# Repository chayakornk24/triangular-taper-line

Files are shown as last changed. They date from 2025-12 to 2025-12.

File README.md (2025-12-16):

# Triangular Taper Transmission Line

This repository contains a complete microwave engineering project
on a triangular taper transmission line, including simulation,
PCB fabrication, and measurement.

The project is documented as a step-by-step report and supported
by simulation and measurement files for reference.

## Project Overview
The work follows a practical engineering workflow:
- Impedance profile design of a triangular taper
- Ideal transmission-line simulation (netlist)
- Electromagnetic geometry simulation
- PCB layout and fabrication
- Measurement using a Vector Network Analyzer (VNA)
- Comparison between simulation and measurement

## Repository Structure
- `report/`
  - Final project report in PDF format (step-by-step explanation)

- `simulation/`
  - Sonnet netlist simulations (ideal models)
  - Sonnet geometry simulations (EM models)
  - Netlist vs geometry comparison

- `measurement/`
  - Measured S-parameter data (.s2p)
  - Measurement and comparison plots

- `pcb/`
  - PCB design information (EasyEDA)
  - Fabrication-related files

## Notes
- The PDF report is self-contained and explains the full process.
- Supporting files in this repository are provided for reference
  and project completeness.

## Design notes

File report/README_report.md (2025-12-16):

# Report (PDF)

This folder contains the final step-by-step project report
for the triangular taper transmission line.

## File
- `Triangular_Taper_Line_Report.pdf`
  - Complete report including:
    - Design workflow
    - Netlist simulation
    - Geometry simulation (original vs expanded box cell)
    - PCB design and fabrication
    - VNA measurement setup and results
    - Simulation vs measurement comparison
    - Summary

## Notes
- The report is self-contained (no external links are required to understand the process).
- Supporting project files are stored in the main repository folders:
  - `simulation/`
  - `measurement/`
  - `pcb/`

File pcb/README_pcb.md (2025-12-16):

The PCB layout of the triangular taper line
was designed using EasyEDA.

Public EasyEDA project link:
https://easyeda.com/editor#project_id=84cbbce2f2da43b88b3fbd5d7b5f4b61

This link allows viewing, modification,
and reproduction of the PCB design.

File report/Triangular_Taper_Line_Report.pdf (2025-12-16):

## Title: Triangular Taper Line Design Course: Microwave Engineering - 01205322 Tools: Sonnet, TXLine2003, EasyEDA, JLCPCB Name: Chayakorn Kaewpinit Student ID: 6610550794 Date: 15/12/2025

## Introduction

### This work designs a Triangular taper transmission line and compares 10-section and 20-section implementations. The process follows a practical engineering

workflow from impedance calculation to simulation and PCB fabrication.

## Design Overview (workflow)

### 1. Compute impedance profile (Triangular taper)

### 2. Sonnet netlist simulation (10 vs 20 sections)

### 3. Convert impedance → physical dimensions using TXLine2003 (W, L, and CPW-G spacing)

### 4. Sonnet geometry simulation (20 sections)

### 5. Export to PCB layout (EasyEDA) and fabricate via JLCPCB

# Impedance profile method

We generate the taper impedance using a Triangular weighting with an exponential impedance mapping from 50 Ω to 100 Ω.

### Midpoint location of each section

xi =

i −

1
2
N

, i = 1,2, … , N

### Triangular cumulative function (piecewise)

G(x) = {

2x

2
| if 0 ≤ x ≤ 0.5
4x − 2x | 2 − 1 if 0.5 < x ≤ 1

}

### Exponential impedance mapping

## Z(x) = Z1 (

Z2
Z1

)

G(x)

## , (Z1 = 50 Ω , Z2 = 100 Ω)

### Worked example (i=1, N=10)

### Midpoint position

x1 =

1 −

1
2
10 = 0.05

### Since x1 ≤ 0.5

G(x1

) = 2x1

2 = 2(0.05)
2 = 0.005

### Compute impedance

Z1 = 50 (

100
50 )

0.005
= 50 ∗ 2

0.005

### Numeric value

2

0.005 = 1.0034717

Z1 = 50(1.0034717) = 50.17 Ω

i | (x_i) | (G(x_i)) | (Z_i) (Ω)
1 | 0.05 | 0.005 | 50.17
2 | 0.15 | 0.045 | 51.59
3 | 0.25 | 0.125 | 54.53
4 | 0.35 | 0.245 | 59.34
5 | 0.45 | 0.405 | 65.97
6 | 0.55 | 0.595 | 74.5
7 | 0.65 | 0.755 | 84.25
8 | 0.75 | 0.875 | 91.78
9 | 0.85 | 0.955 | 96.96
10 | 0.95 | 0.995 | 99.83

# Netlist simulation

The calculated impedances are modeled as cascaded transmission line sections in Sonnet netlist to observe ideal electrical behavior.

### 10 sections

: 10-section taper is close to ideal but still shows ripple / higher reflection.

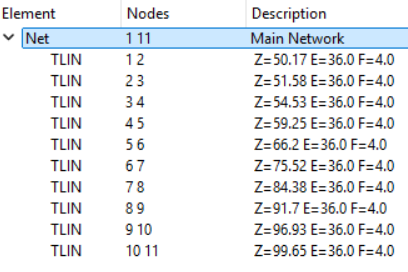
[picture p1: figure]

### 20 sections

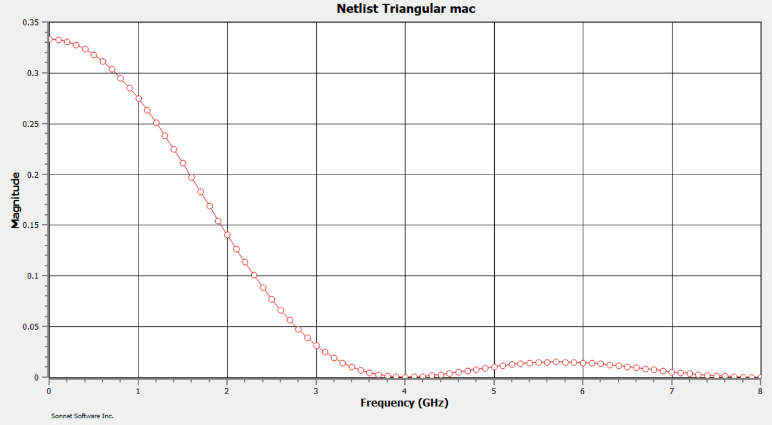
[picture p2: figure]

: 20-section taper reduces reflection and becomes smoother / closer to ideal.

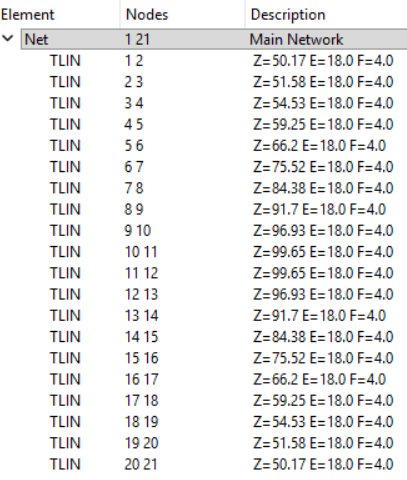
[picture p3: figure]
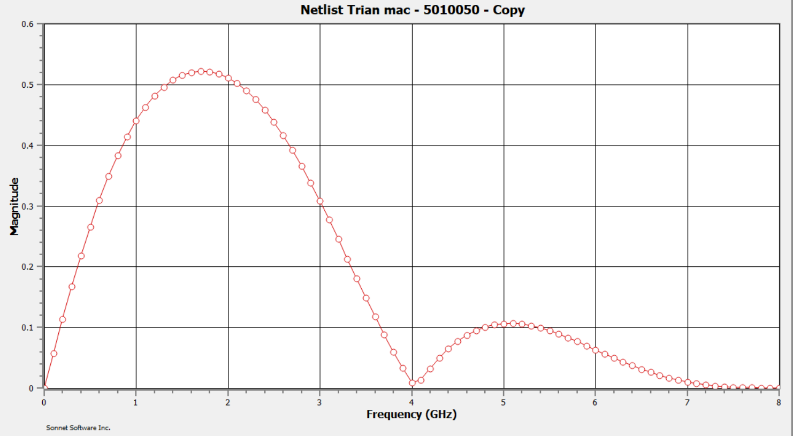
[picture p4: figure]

# Dimensions + CPW-Ground Spacing

### TXLine2003 conversion

The 20-section impedance values are entered into TXLine2003 to obtain physical dimensions under the same substrate settings.

Main outputs used

- Signal width W
- Section length L

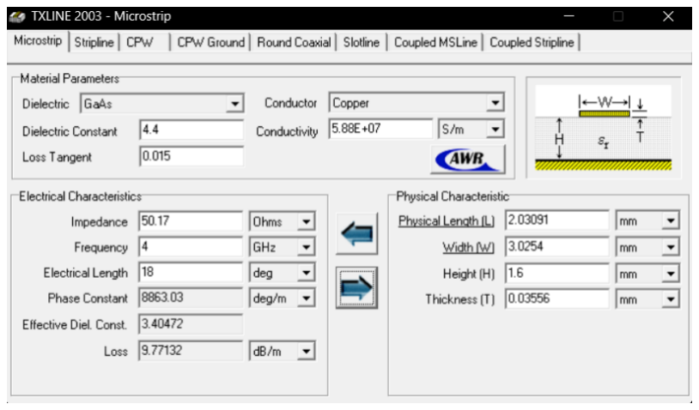
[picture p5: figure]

- For CPW with ground (CPWG): spacing S between the center conductor and both ground conductors (two side grounds)
Impedance | W | L
50.17 | 3.0254 | 2.03091
51.58 | 2.88555 | 2.03577
54.53 | 2.61826 | 2.04565
59.25 | 2.25101 | 2.06064
66.2 | 1.81633 | 2.08099
75.52 | 1.37343 | 2.10539
84.38 | 1.05728 | 2.12572
91.7 | 0.85265 | 2.1407
96.93 | 0.731103 | 2.1506
99.65 | 0.674795 | 2.15554

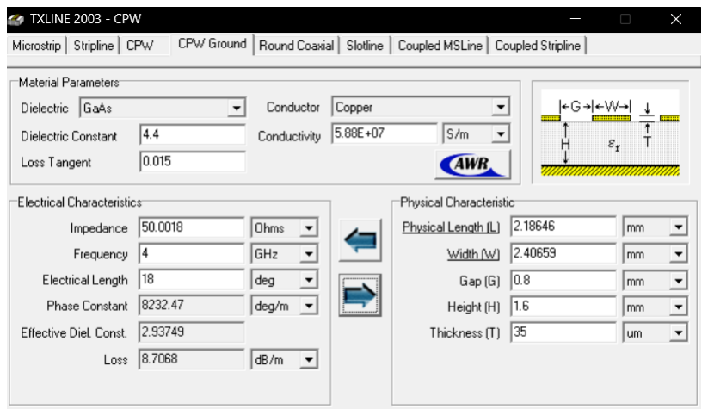
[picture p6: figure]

# Sonnet Geometry Simulation (20 Sections)

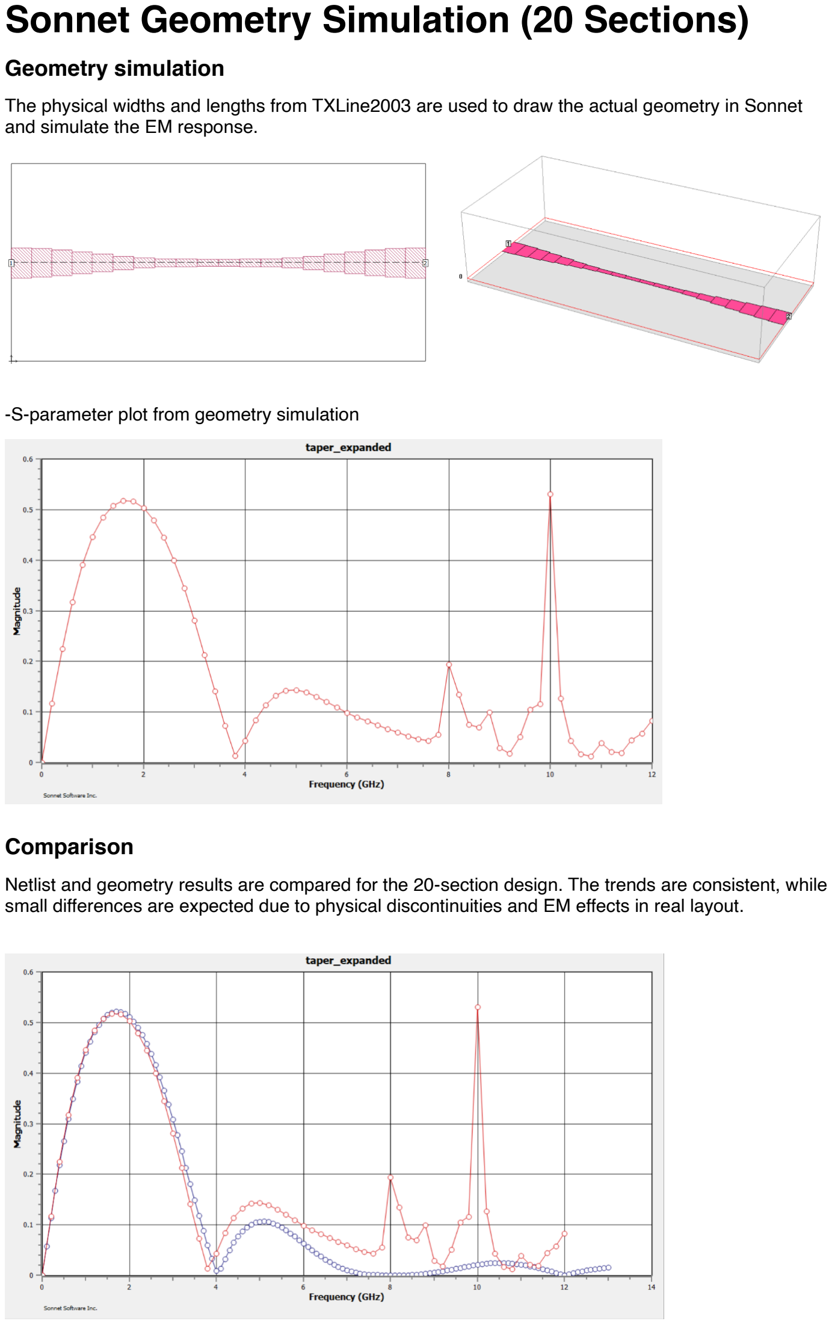
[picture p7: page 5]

### Geometry simulation

The physical widths and lengths from TXLine2003 are used to draw the actual geometry in Sonnet and simulate the EM response.

-S-parameter plot from geometry simulation

### Comparison

Netlist and geometry results are compared for the 20-section design. The trends are consistent, while small differences are expected due to physical discontinuities and EM effects in real layout.

# EasyEDA PCB Layout → JLCPCB

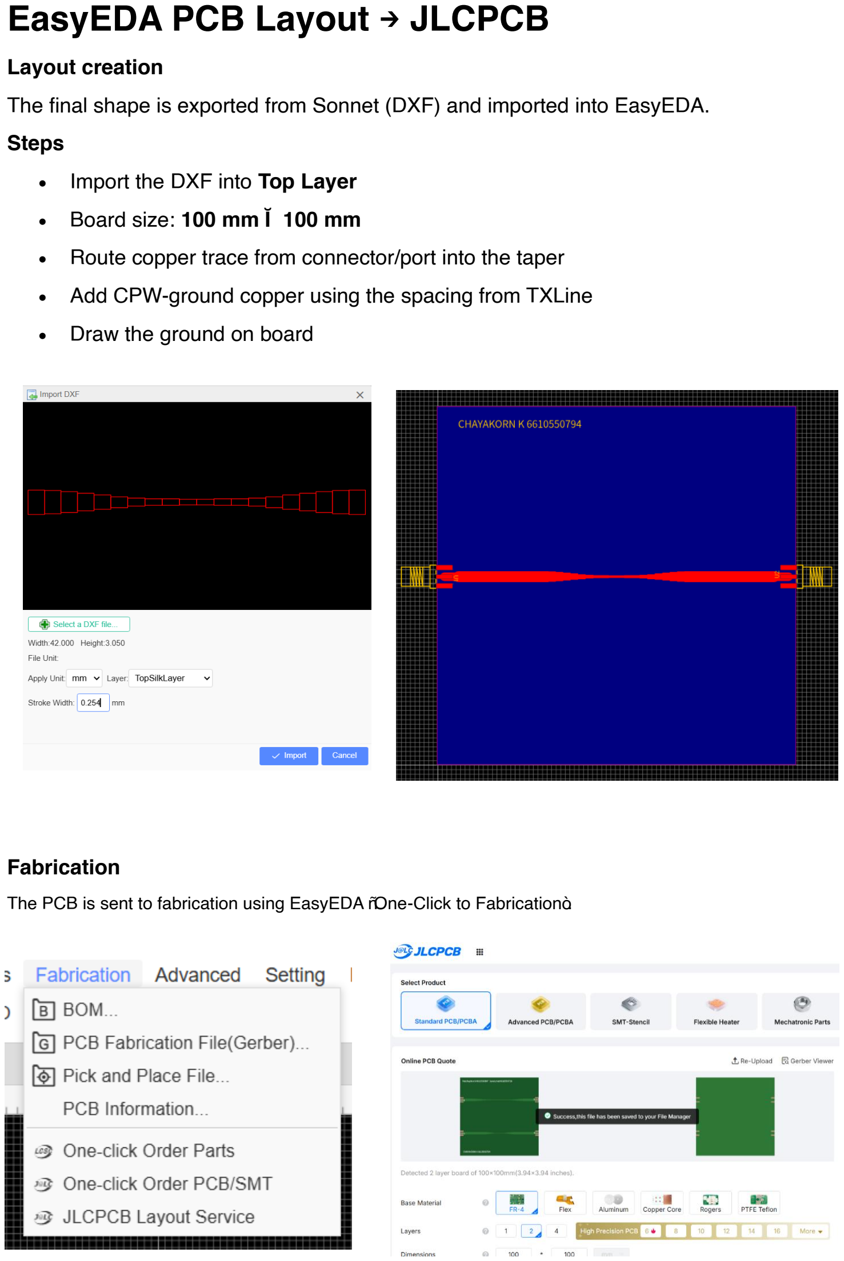
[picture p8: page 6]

### Layout creation

The final shape is exported from Sonnet (DXF) and imported into EasyEDA.

### Steps

### - Import the DXF into Top Layer

### - Board size: 100 mm × 100 mm

### - Route copper trace from connector/port into the taper

### - Add CPW-ground copper using the spacing from TXLine

### - Draw the ground on board

### Fabrication

The PCB is sent to fabrication using EasyEDA “One-Click to Fabrication”.

# PCB Measurement

### PCB Fabrication

This Figure shows the fabricated PCB of the triangular taper line before soldering the connectors. The tapered transmission line was implemented with a continuous change in line width according to the triangular taper profile. This geometry is consistent with the design used in the Sonnet simulation

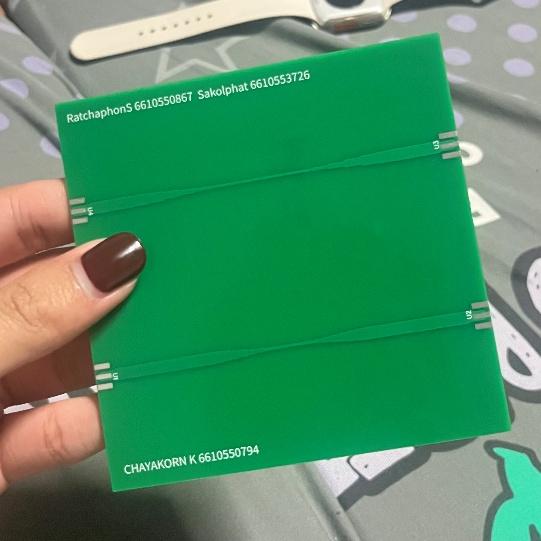
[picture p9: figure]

### Connector Soldering

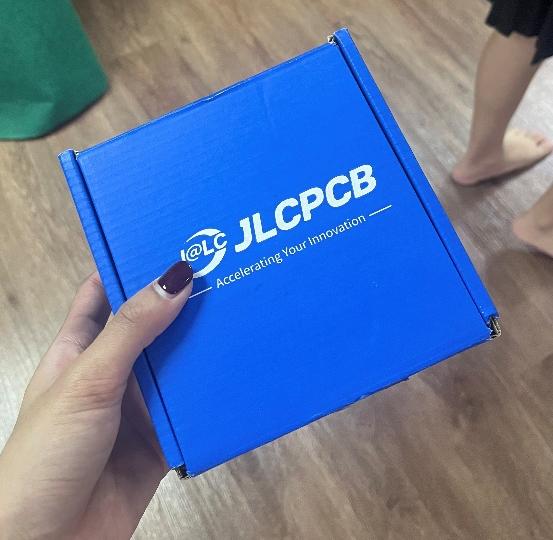
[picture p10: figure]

The SMA connectors were soldered onto the PCB under the supervision of the instructor. Proper soldering is important to ensure good electrical contact and to reduce unwanted effects during measurement.

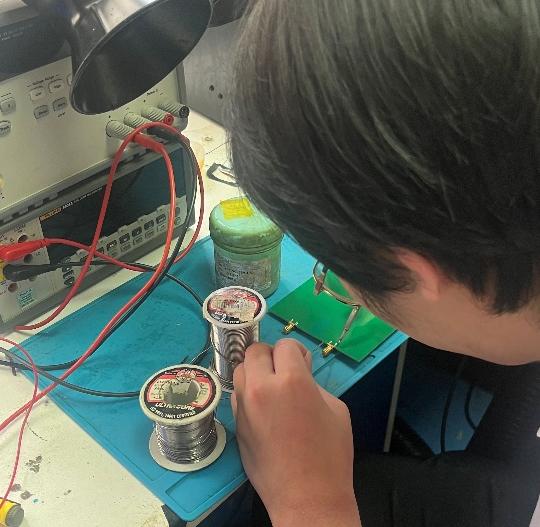
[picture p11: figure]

### Measurement

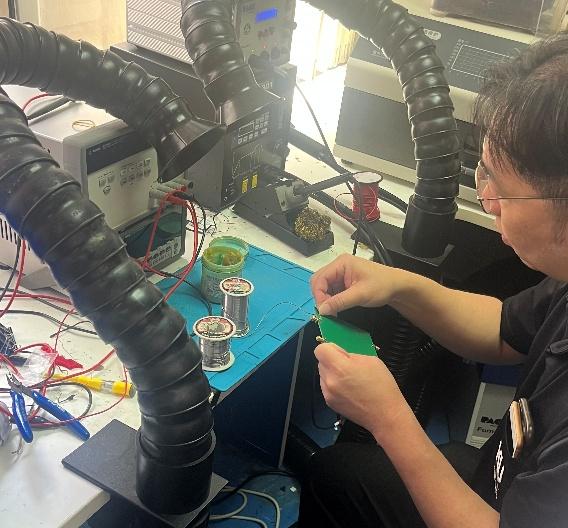
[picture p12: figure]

The fabricated triangular taper line PCB was measured using a Vector Network Analyzer (VNA). The measurement was performed by connecting coaxial cables to both ports of the PCB. The measured S-parameter magnitude represents the real performance of the taper line, including fabrication and measurement effects.

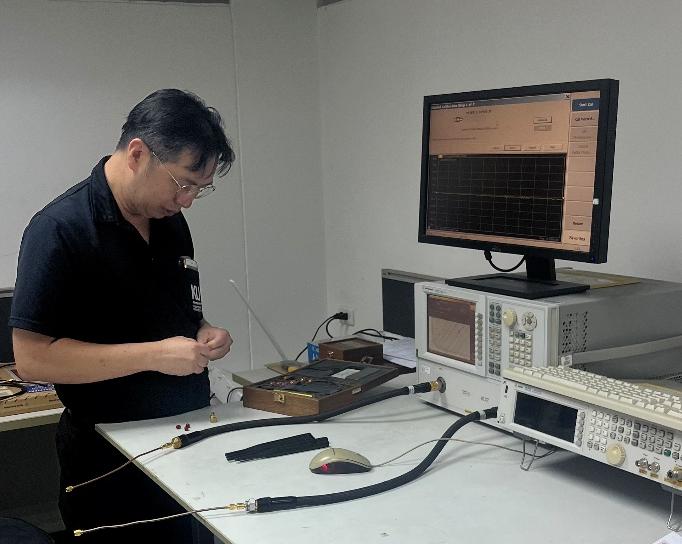
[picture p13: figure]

# Comparison

The measured results are compared with the Sonnet geometry simulation results (red curve) for the 20-section design. The overall trends are in good agreement, showing similar frequency response behavior. Small differences in magnitude and frequency shift are observed, which are expected due to fabrication tolerances, connector effects, and other practical factors in the real measurement.

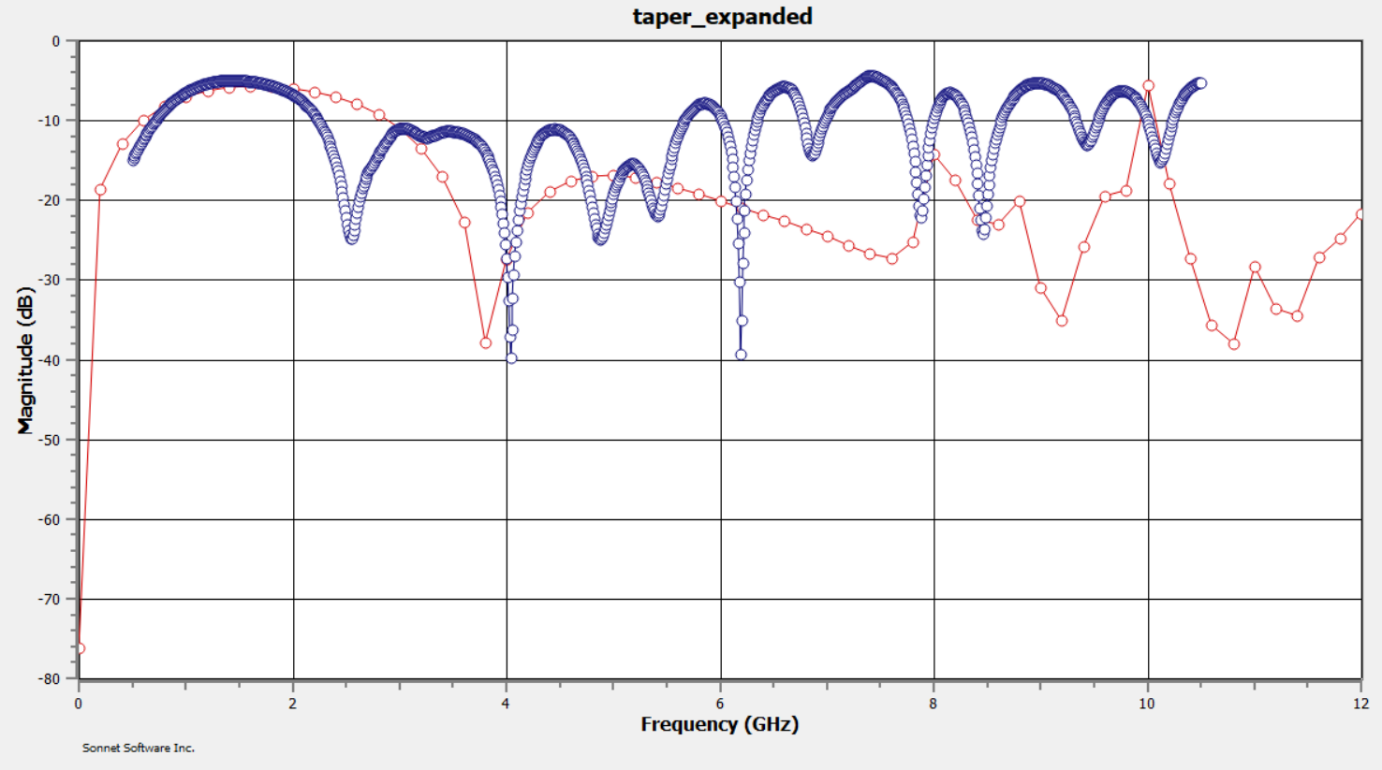
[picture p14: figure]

# Summary

The comparison confirms that the Sonnet geometry simulation provides a good prediction of the triangular taper line behavior. The measured results show the real performance of the fabricated PCB and include practical effects that are not fully modeled in the simulation.

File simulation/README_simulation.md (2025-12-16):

This folder contains simulation files for the
triangular taper transmission line.

Two types of simulations are provided.

1. Netlist Simulation (Ideal Transmission Line Model)
   Netlist simulations are used as an ideal
   electrical reference without geometry effects.

   - 10 sections, 50 to 100 ohm
     simulation/netlist/10_sections_50to100/

   - 20 sections, 50 to 100 to 50 ohm
     simulation/netlist/20_sections_50to100to50/

   The 20-section netlist simulation is used
   as the reference for comparison with
   geometry-based simulations.

2. Geometry Simulation (EM Model)
   Geometry simulations include electromagnetic
   effects and are used to study the impact
   of physical layout and boundary conditions.

   - Original box cell
     simulation/geometry/original_box/

   - Expanded box cell
     simulation/geometry/expanded_box/

3. Simulation Comparison
   The 20-section netlist simulation is compared
   with both geometry simulation configurations
   to evaluate the effects of geometry and
   simulation boundary.

   - simulation/comparison/

The expanded box cell geometry simulation
was used for the final comparison with
measurement results.

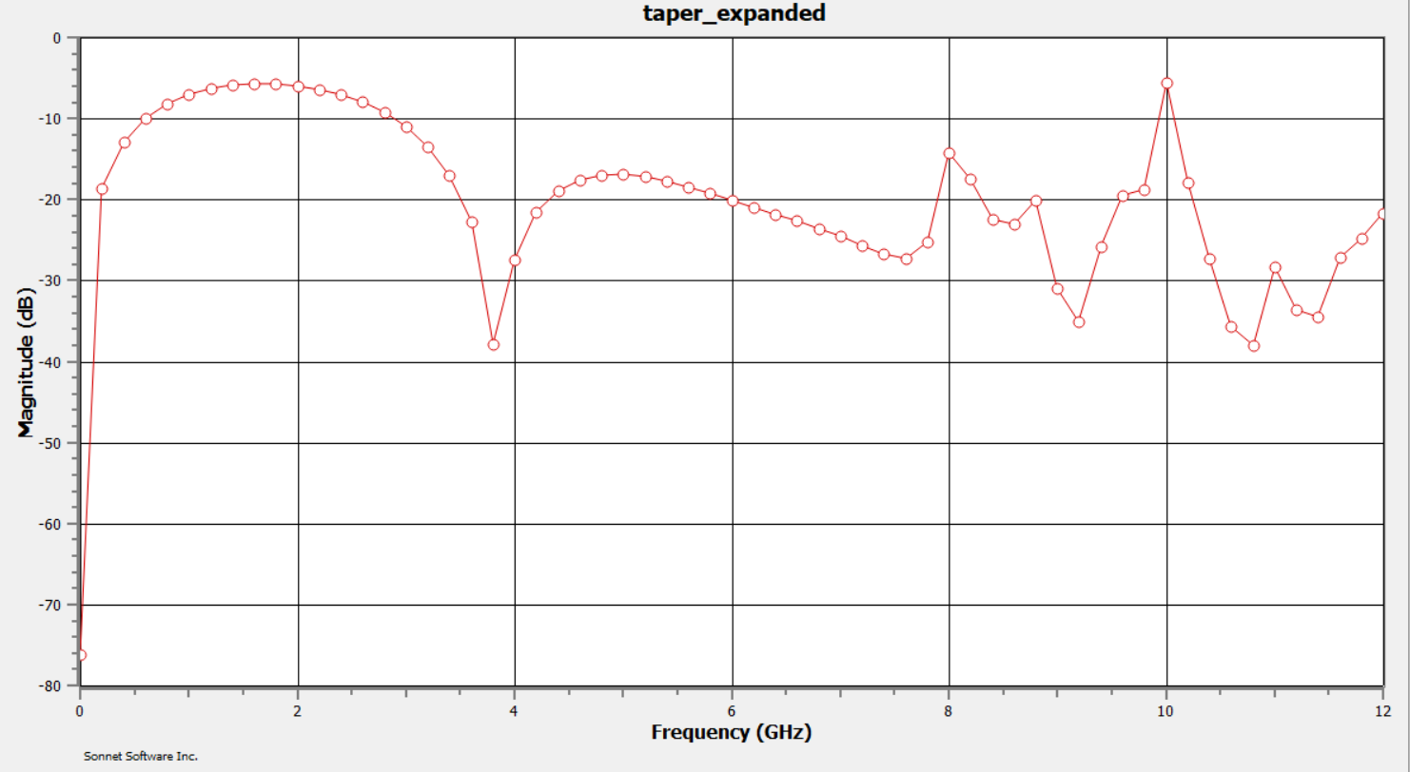
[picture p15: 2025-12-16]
simulation/simulation/geometry/simulation/geometry/expanded_box/Tapersimulationexpanded.png

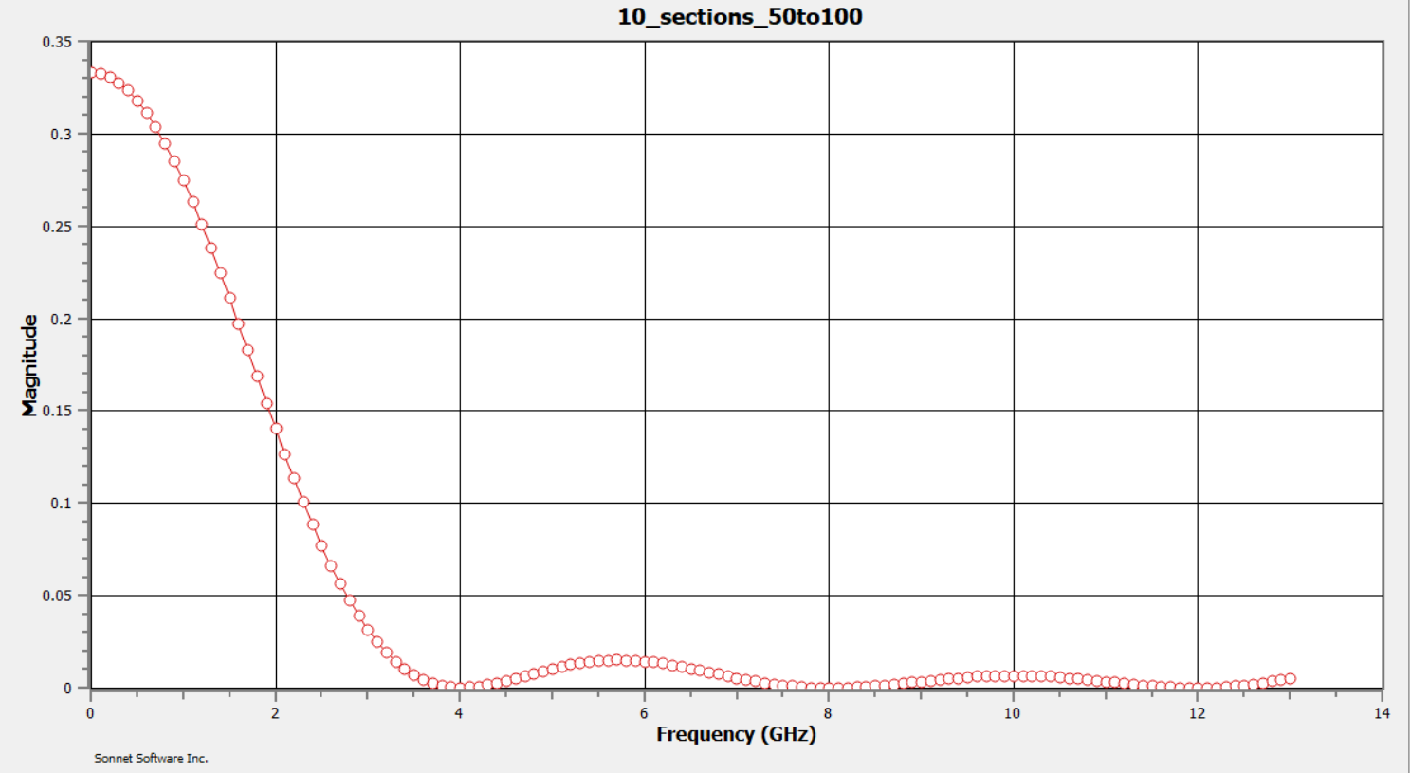
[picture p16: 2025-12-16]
simulation/simulation/netlist/simulation/netlist/10_sections_50to100/10_sections_50to100 ( Magnitude ).png

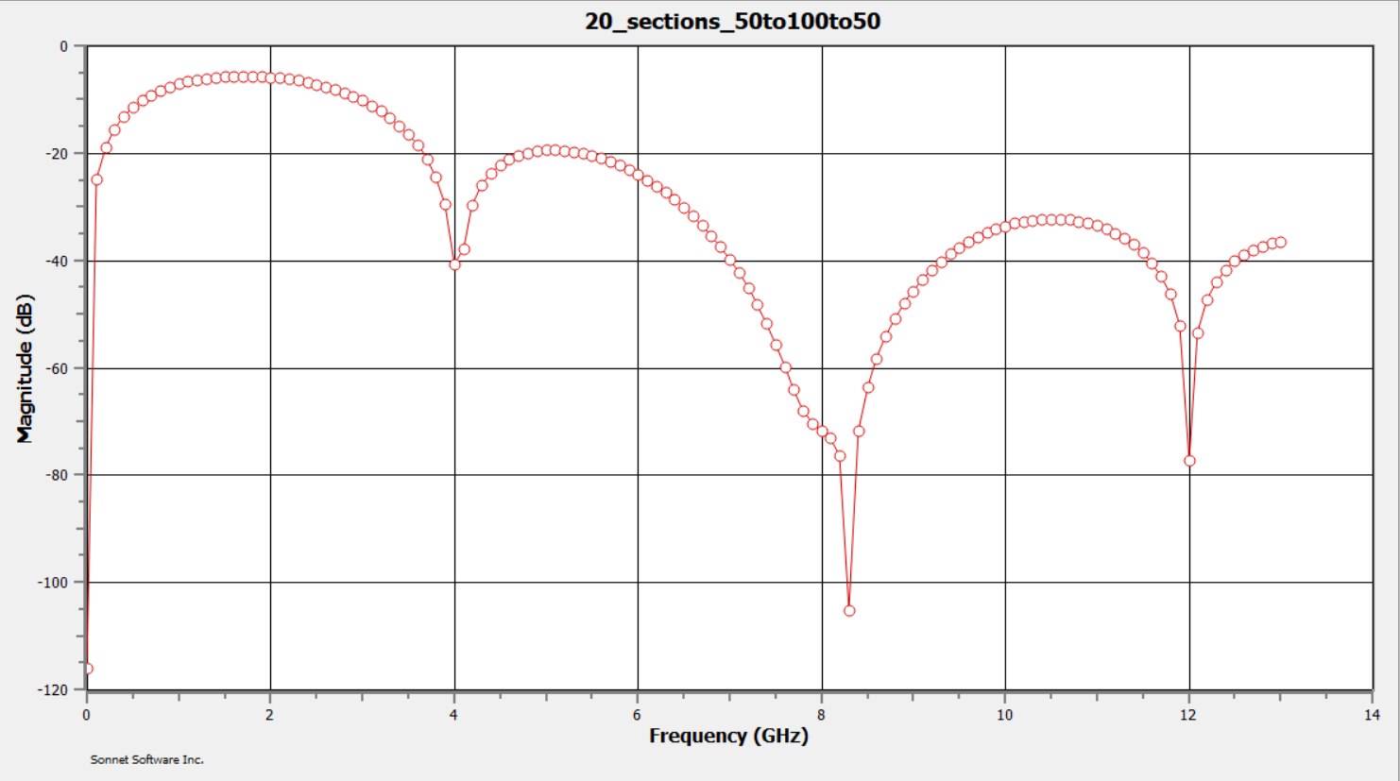
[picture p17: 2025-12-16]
simulation/simulation/netlist/simulation/netlist/20_sections_50to100to50/20_sections_50to100to50 ( dB ).png

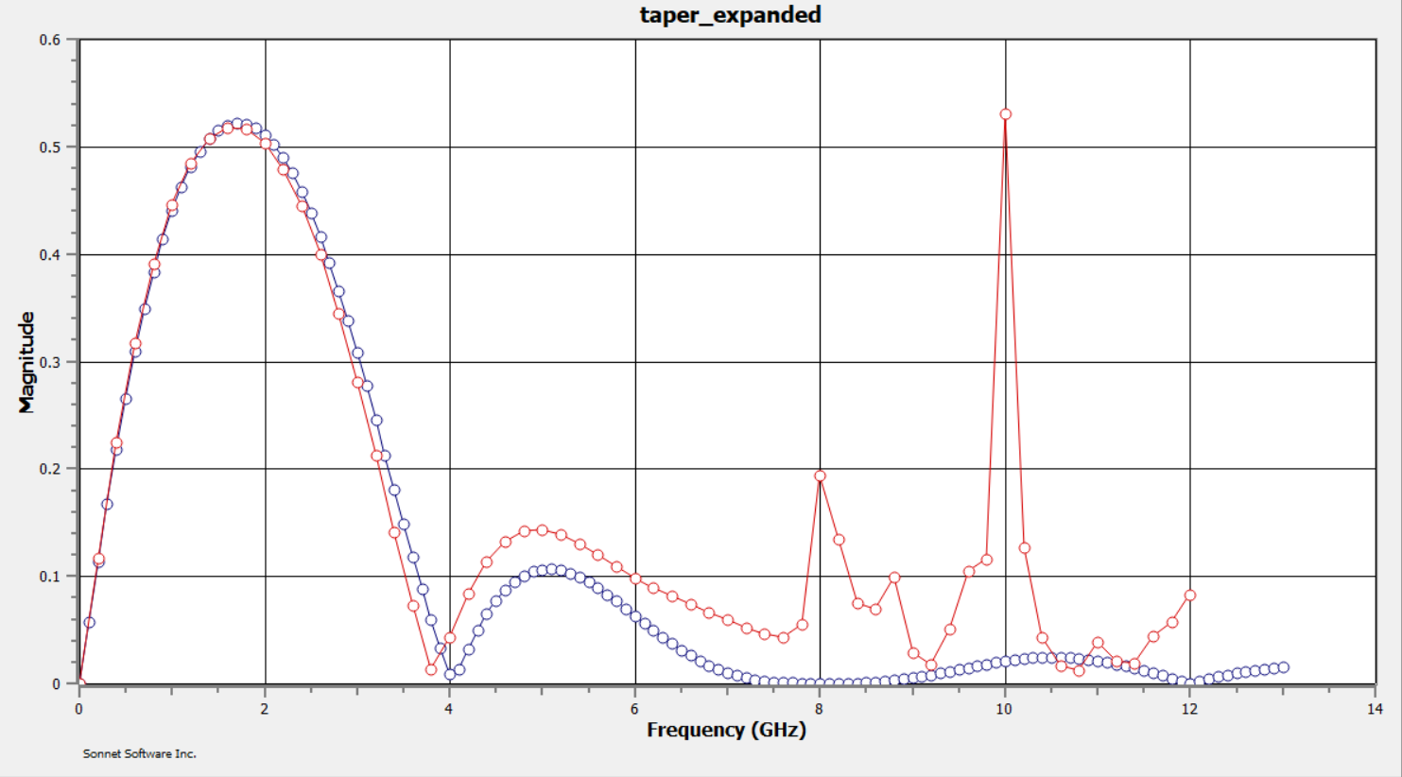
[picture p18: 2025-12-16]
simulation/comparison/netlist_vs_geometry_expanded in Magnitude .png

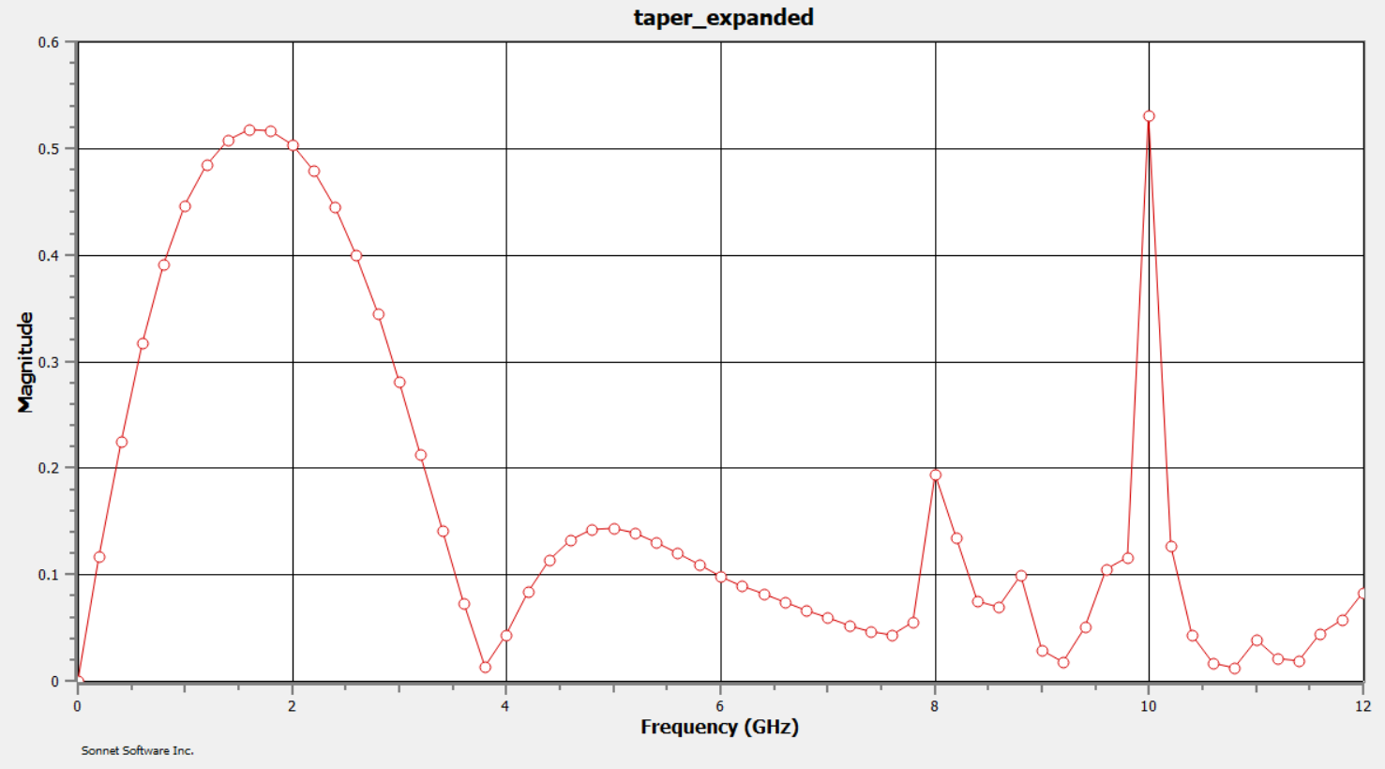
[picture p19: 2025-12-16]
simulation/simulation/geometry/simulation/geometry/expanded_box/Tapersimulationexpanded(magnitude).png

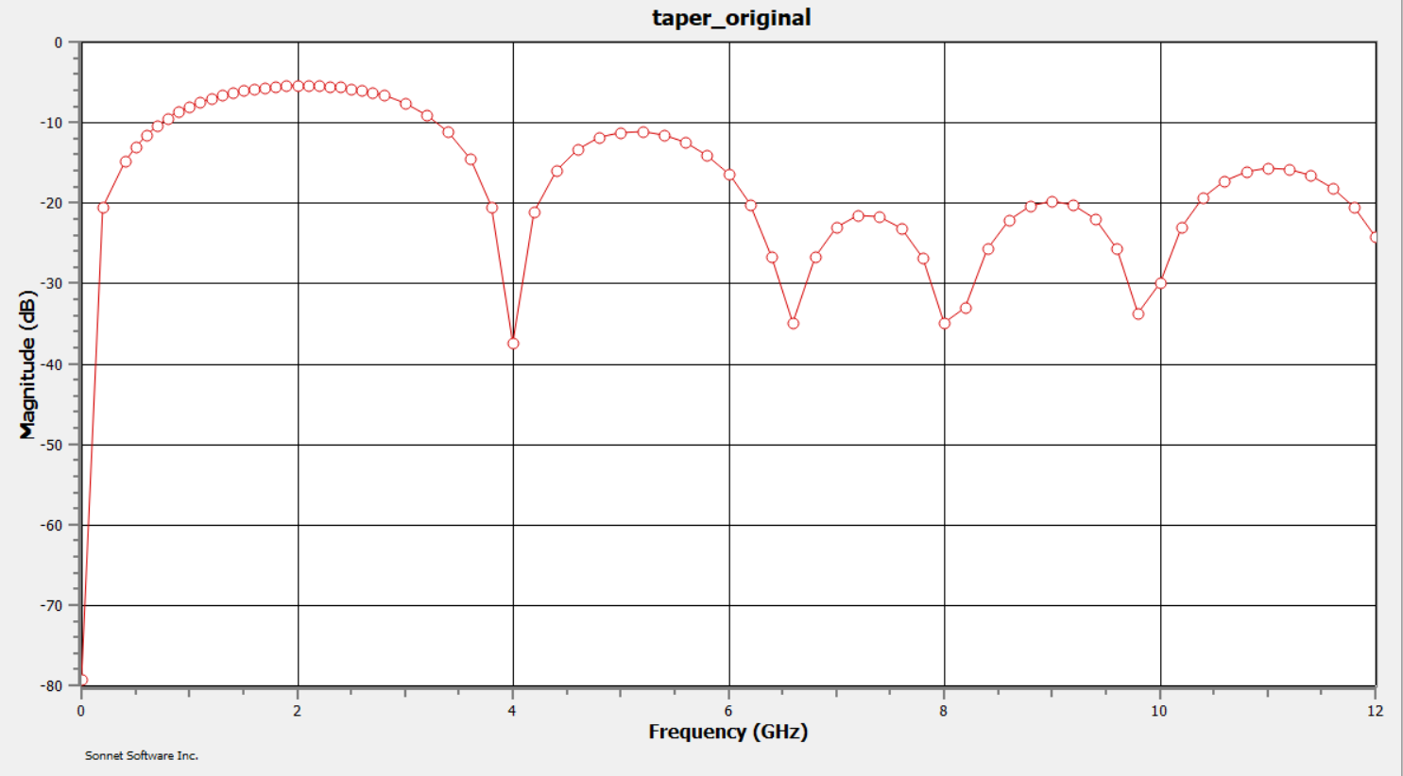
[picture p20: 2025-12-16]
simulation/simulation/geometry/simulation/geometry/original_box/Tapersimulationoriginal.png

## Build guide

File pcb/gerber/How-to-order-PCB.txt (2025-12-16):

How to Order PCB

Please refer to:
https://docs.easyeda.com/en/PCB/Order-PCB

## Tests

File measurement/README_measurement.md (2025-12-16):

This folder contains measured S-parameter data
obtained from the fabricated triangular taper
line using a Vector Network Analyzer (VNA).

Files included:
- measured.s2p : Measured results
- measurement_plot.png : Measured results
- comparison_plot.png : Comparison with geometry simulation

The measured results are compared with the
expanded box cell geometry simulation.
